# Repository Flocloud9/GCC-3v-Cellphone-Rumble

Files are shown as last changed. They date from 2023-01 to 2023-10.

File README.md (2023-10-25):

# **GCC-3v-Cellphone-Rumble**

3v Cellphone Rumble Bracket for the GCC and Phob GCC project.

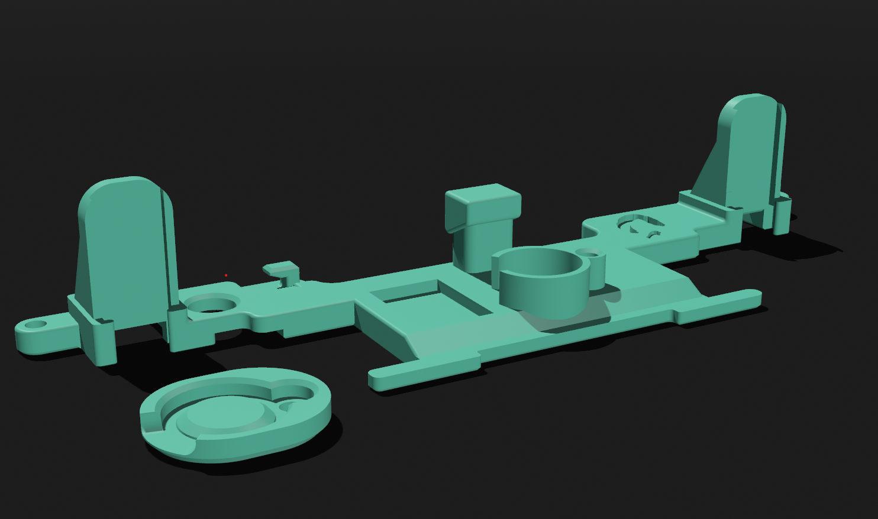
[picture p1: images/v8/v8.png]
Bracket Version 8!


## **An open source 3v "Cell-phone" Rumble Bracket for the PHOB & GCC with...**

-   compatible with either 3v Buck Converter or \~23 ohm resistor
-   Mouse click L/R compatibility
-   Cutout for OEM and snapback mod wires
-   L-cut hole for Phob 1.2.X teensy pins
-   Cell rumble mount with screw on lid
-   Open Source! Just throw me some credit on derivatives @abeartus :)
-   Shap3r editable files included!

## **required parts**

-   3-4x M1.6 Heat inserts [McMaster](https://www.mcmaster.com/92120A150/)

-   3-4x M1.6 Screw [McMaster](https://www.mcmaster.com/90910A901/)

-   1x 3v cellphone motor [Amazon](https://a.co/d/5VttFeg) [AliExpress](https://www.aliexpress.us/item/3256803801626556.html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)

*Pick one of the two methods for stepping down the controllers 5v out to the cell rumble's 3v*

**Resistor Method**

-   1x 25ohm resister [Amazon](https://a.co/d/4aCmpb3) (just need the 22ohm)

-   1x small 3:1 Heat shrink [Amazon](https://a.co/d/0B9l2j5)
 
**Buck Converter Bracket**

-   recommended : 1x 3v Buck converter not soldered [AliExpress](https://www.aliexpress.us/item/2251832865440609.html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)
-   or
-   1x 3v Buck converter pre soldered [Amazon](https://a.co/d/hcY47oe) [AliExpress](https://www.aliexpress.us/item/3256802643066285.html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,scm-url:1007.40000.317745.0,pvid:9f4be090-9cd5-447a-85e5-b2ded161dbb8,tpp_buckets:668%232846%238110%23324&pdp_ext_f=%7B%22sku_id%22%3A%2212000030781473442%22%2C%22sceneId%22%3A%2230050%22%7D&pdp_npi=2%40dis%21USD%210.01%210.01%21%21%21%21%21%402101f6b716734767897904494edef0%2112000030781473442%21rec)

## **Guide**

### **1. Get a copy of the Bracket and Lid printed**

-   I usually print in PLA+, However regular pla, and rigid resins should work for the bracket

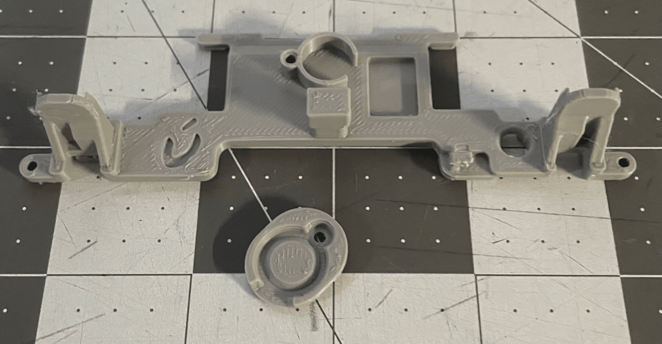
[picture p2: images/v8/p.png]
    

-   If printing on your own home machine with Cura I recommend doing support blocking around the L-cut on the bottom for the Phob 1's Teensy pins.

    1.  Select the bracket in Cura

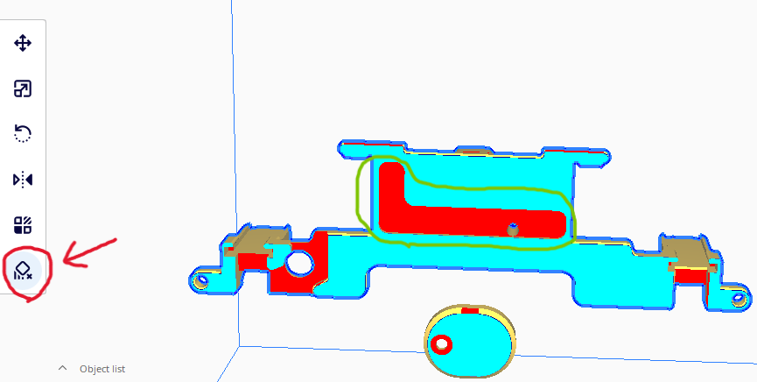
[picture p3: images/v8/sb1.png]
        

    2.  Put the support blocking around the L-Cut channel

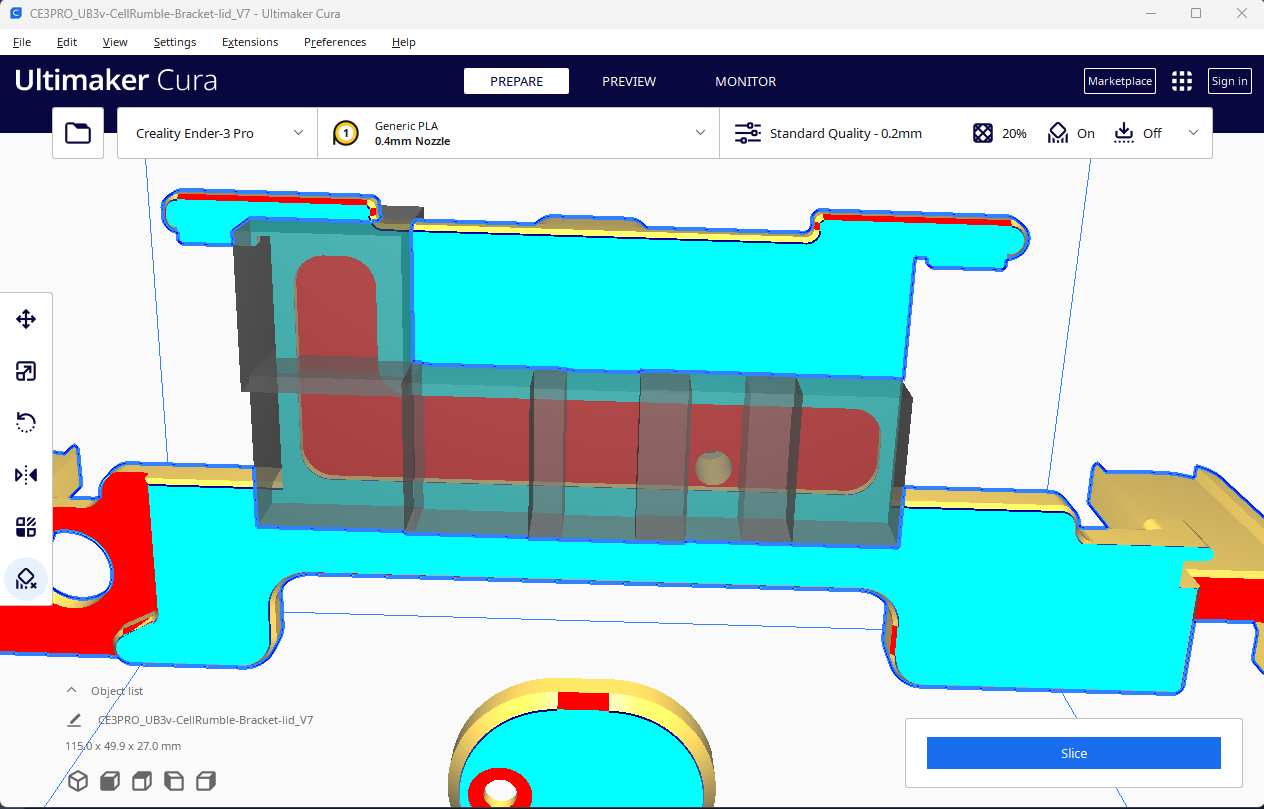
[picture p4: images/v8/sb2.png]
        

### **2. Prep the cellphone motor**

**!!** *Use one of the two methods to step down the 5v to 3v* **!!**

#### **Resistor**

  1.  Cut the motor lead short

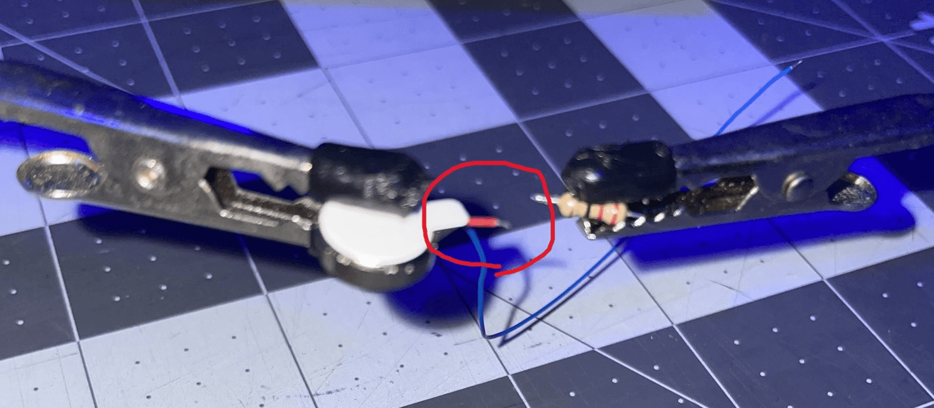
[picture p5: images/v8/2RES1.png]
      

  2.  splice in the \~23 ohm resistor

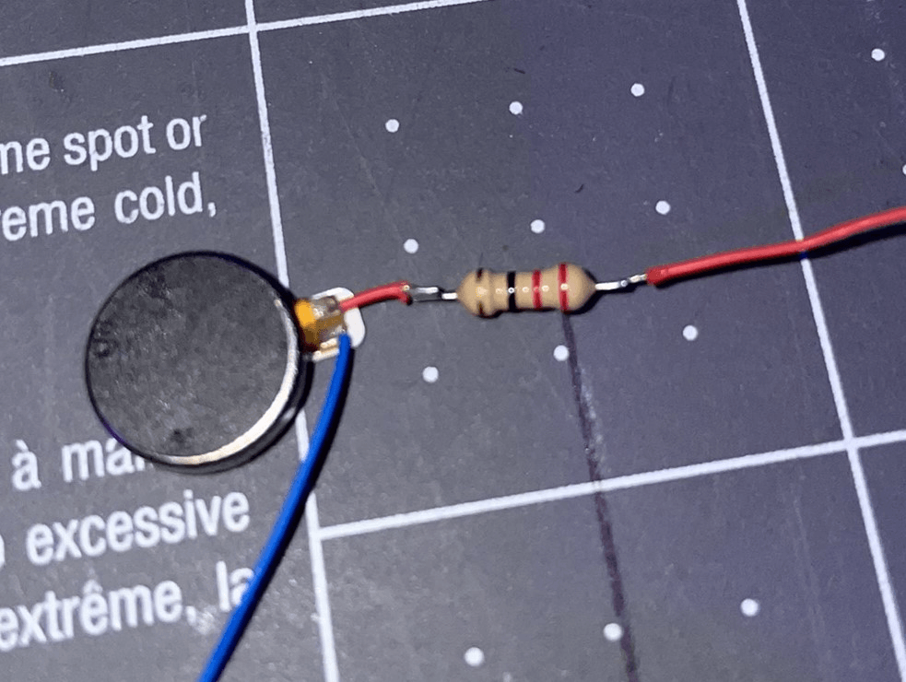
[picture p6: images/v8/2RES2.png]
      

  3.  Heat shrink over the connections/resistor

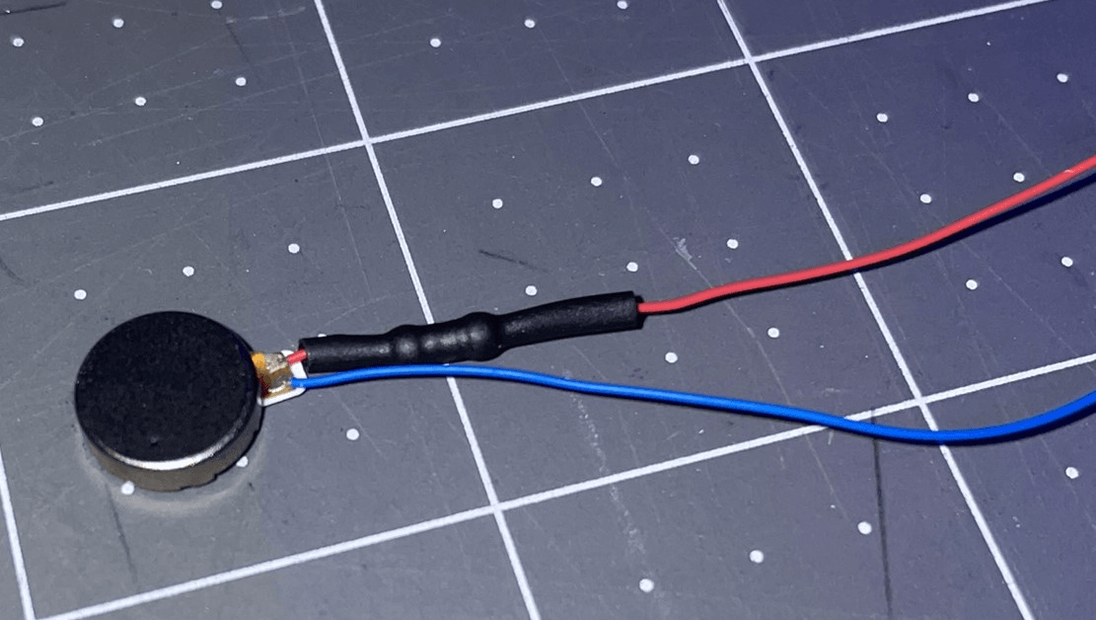
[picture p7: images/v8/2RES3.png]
      

#### **Buck Converter**

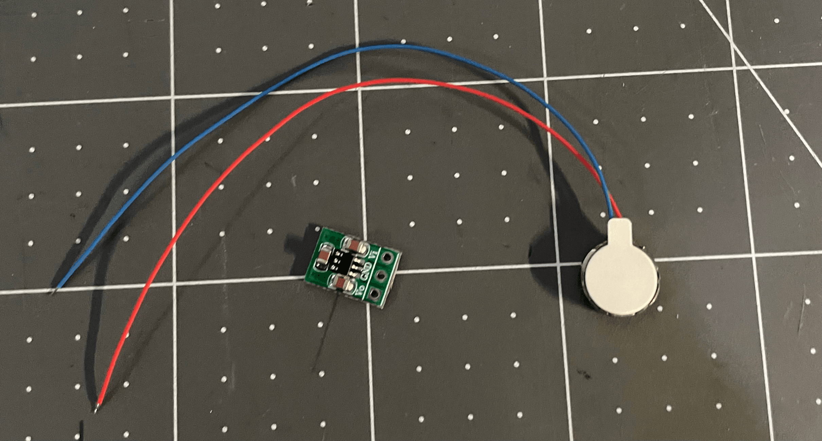
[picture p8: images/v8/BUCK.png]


  1.  Cut the motor leads short, I recycle the remaining wire for the other two connections *(you will need to buy the longer wire motor for this though)*

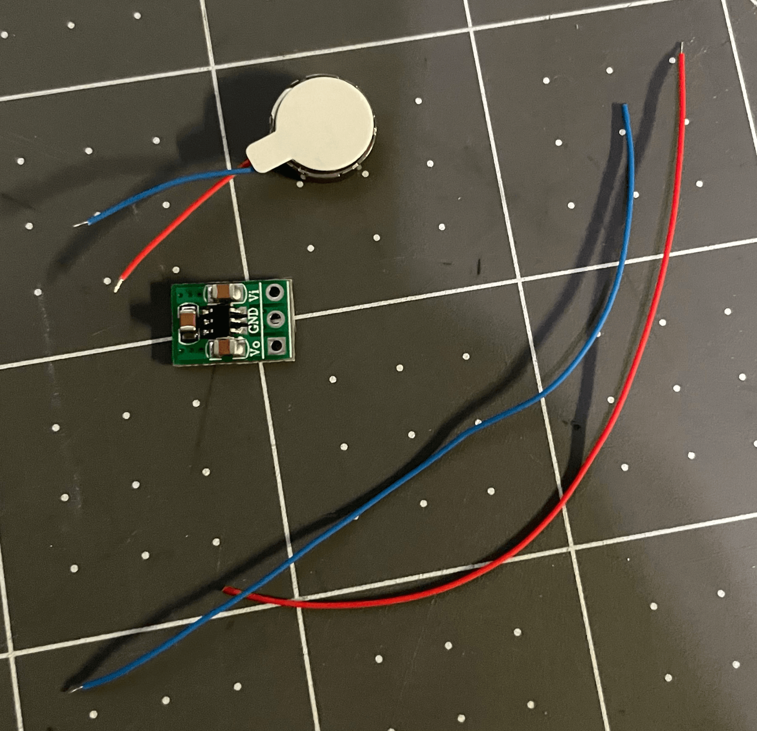
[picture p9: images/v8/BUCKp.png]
      

  2.  Solder the motor positive to the Buck Converter's **v**<sub>0 *(voltage out)*

  3.  Solder the motor negative, and another negative wire to the buck converter's **GND**

  4.  Solder a positive wire onto the Buck Converters **V**<sub>i *(Volatage in)*

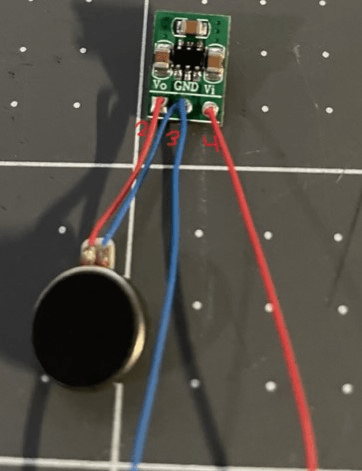
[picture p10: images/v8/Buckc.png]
      

  5.  Try to keep the bottom of the buck converter as flush as possible if using the smaller variety

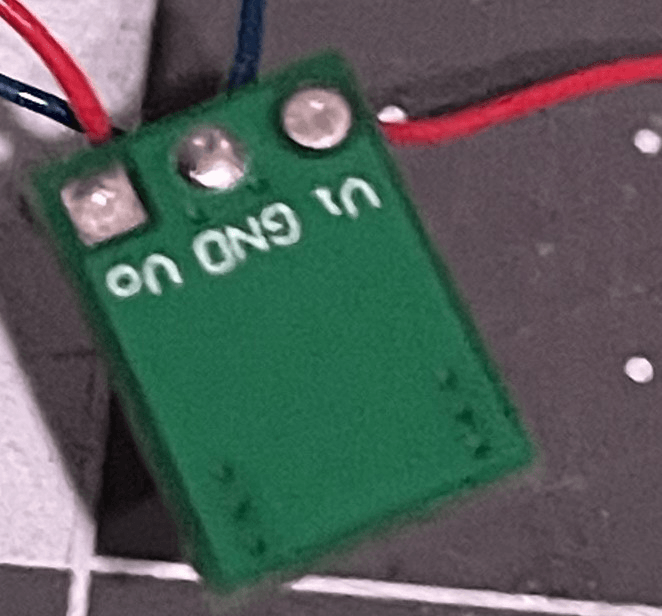
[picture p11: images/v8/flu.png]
      

### **3. Insert the motor into the bracket**

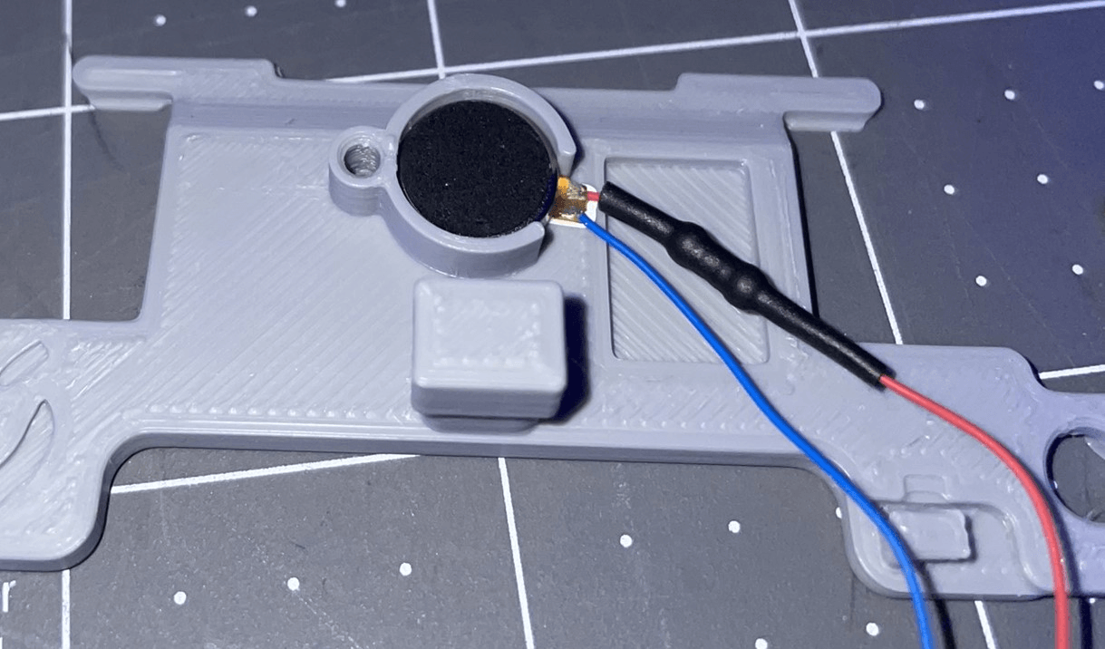
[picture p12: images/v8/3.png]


-   Extra step if using a buck converter

    1.  Glue the buck converter into the dugout to the right of the rumble housing. (I would recommend using some hot glue to hold it into place, super glue tends to ruin the buck converter for some reason when I use it)

### **4. Insert the Threaded Heat Inserts**

-   Using a soldering iron at around 200c or as low as possible with a small tip that can slot into the insert. push the three inserts into the Bracket.

-   The inserts should be pushed in on whatever side it will be screwed in from. So one pushed in from the top, and two on bottom. The proper side has a fillet around the slot that will make the insert easier to place at first.

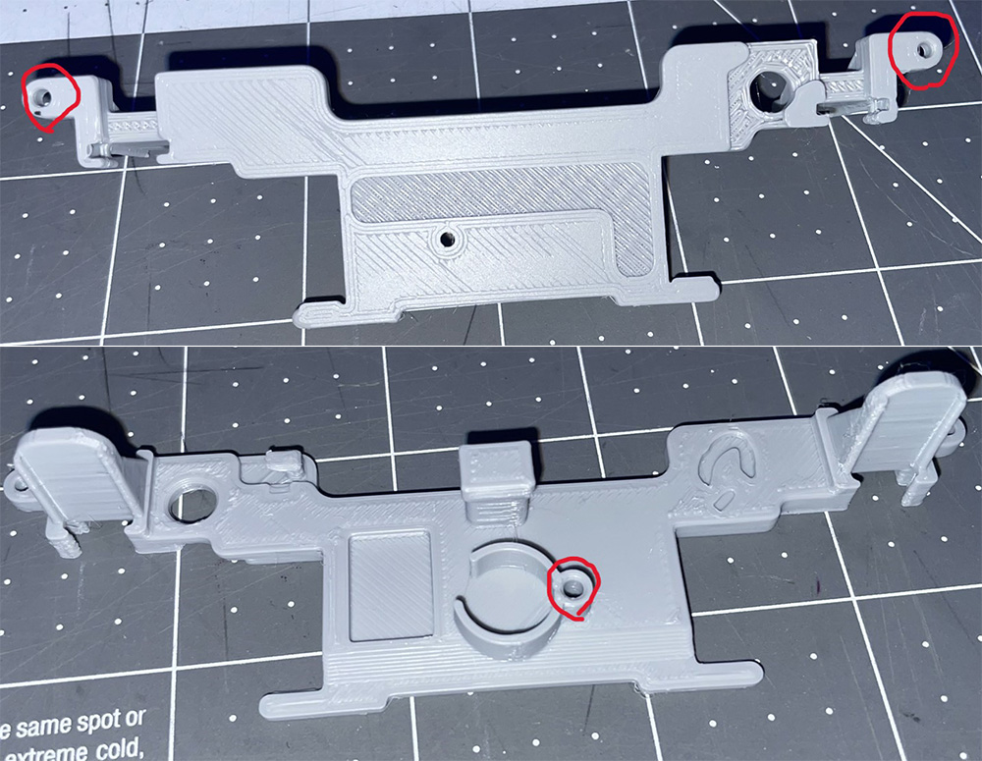
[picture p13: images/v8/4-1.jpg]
    

-   Personally I will set the insert into the brackets slot, then carefully push the insert in trying to be as perpendicular with the bracket as I can.

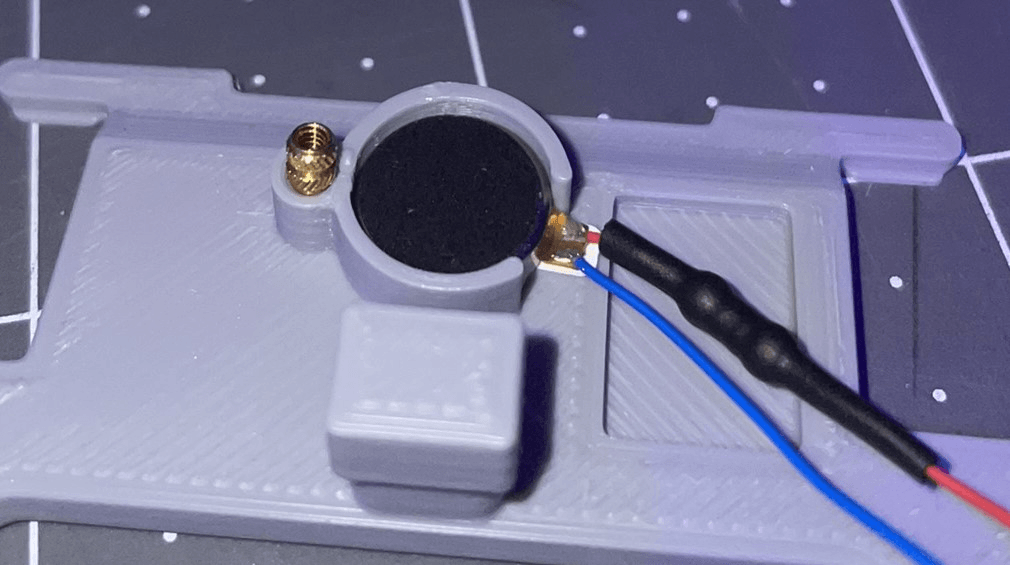
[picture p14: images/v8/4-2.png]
    

-   the bottom ones can be tricky, I usually just flip the bracket over and put the slotted tab onto the table, then I use the method above.

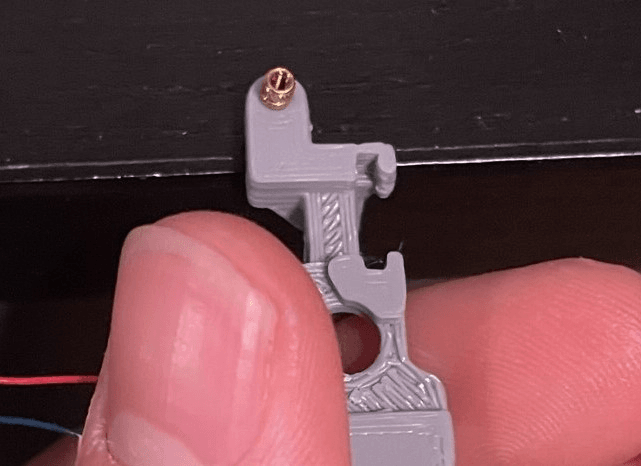
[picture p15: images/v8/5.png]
    

-   This Is what the threads should look like after insertion

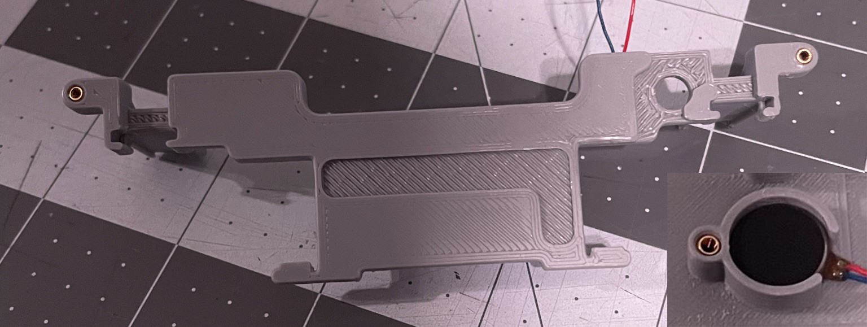
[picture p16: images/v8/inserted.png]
    

### **5. Attach the lid motor's lid to the Bracket**

1.  (semi-optional) I would recommend using some hot glue to help dampen any rattle from the lid and motor, and protect the short motor connection to the resistor.

    -   This is how I apply hot glue

    1.  *(only for my method of splicing in the resistor)* Put a small amount of glue here just to protect the wire from yanking and damaging the resistor splice and motor connection
    2.  *(optional)* Apply a light amount of hot glue here, then while the glue is hot press the rumble motor housing lid into place

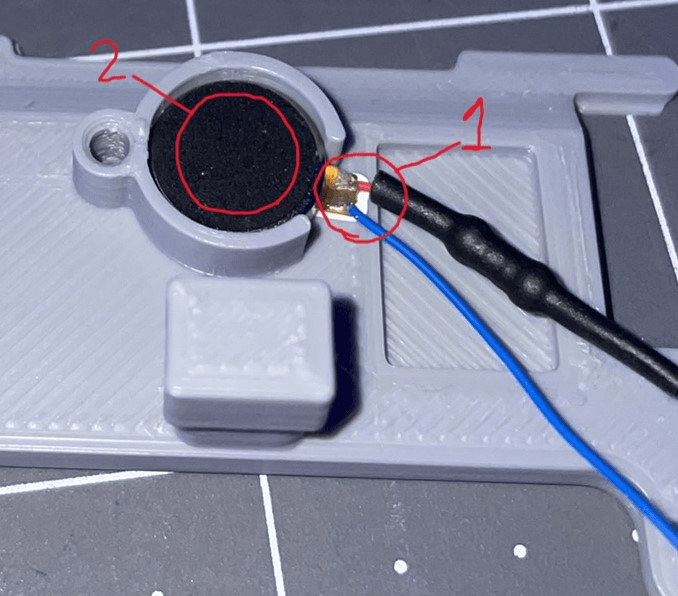
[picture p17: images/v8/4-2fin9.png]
    

2.  Screw the lid into place with one of the three m1.6 screws

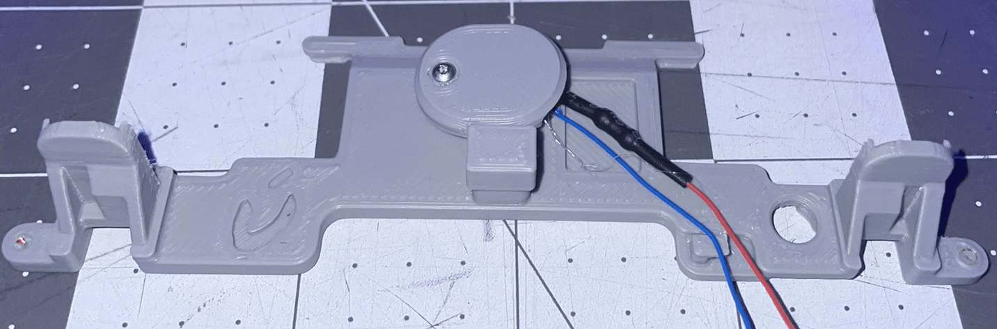
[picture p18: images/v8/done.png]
    

### **6. Solder the Bracket onto the board**

... just like oem ...

### **7. Attach the Bracket onto the board**

I clip the top wings over the L\R sliders then pull the bottom over and onto the pcb

### **8. Screw the bracket into place with the remaining two screws**

Screw it :))

## **Credit**

-   similar guide by fires on [his bracket](https://firescc.com/mod-guides#/rumble-bracket), mine is similar, so credit to fires

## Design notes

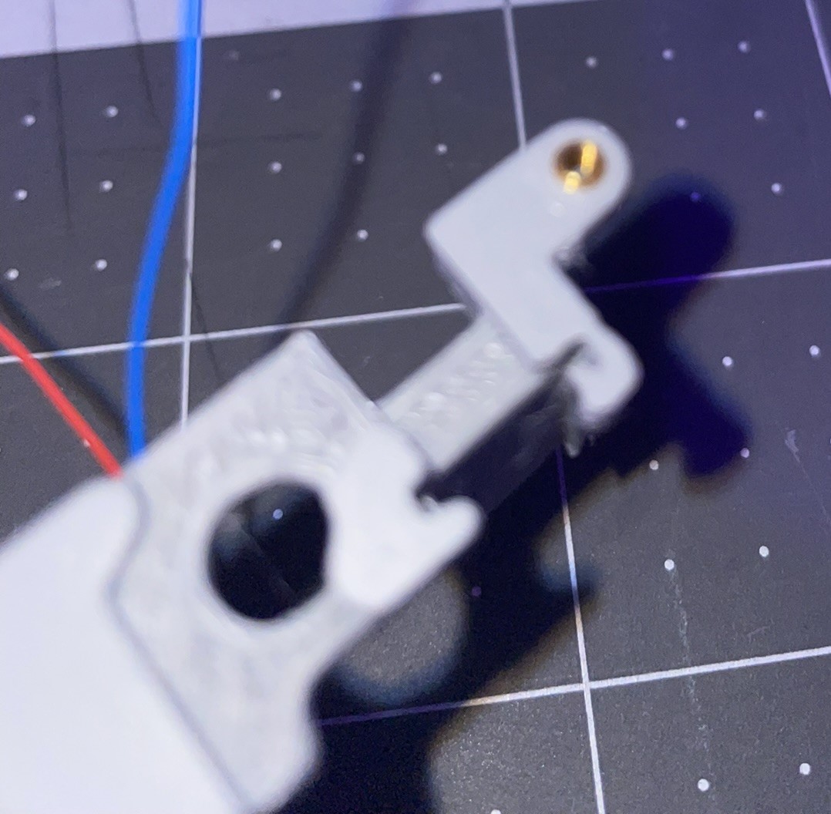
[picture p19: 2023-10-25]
images/v8/4botfin.JPEG

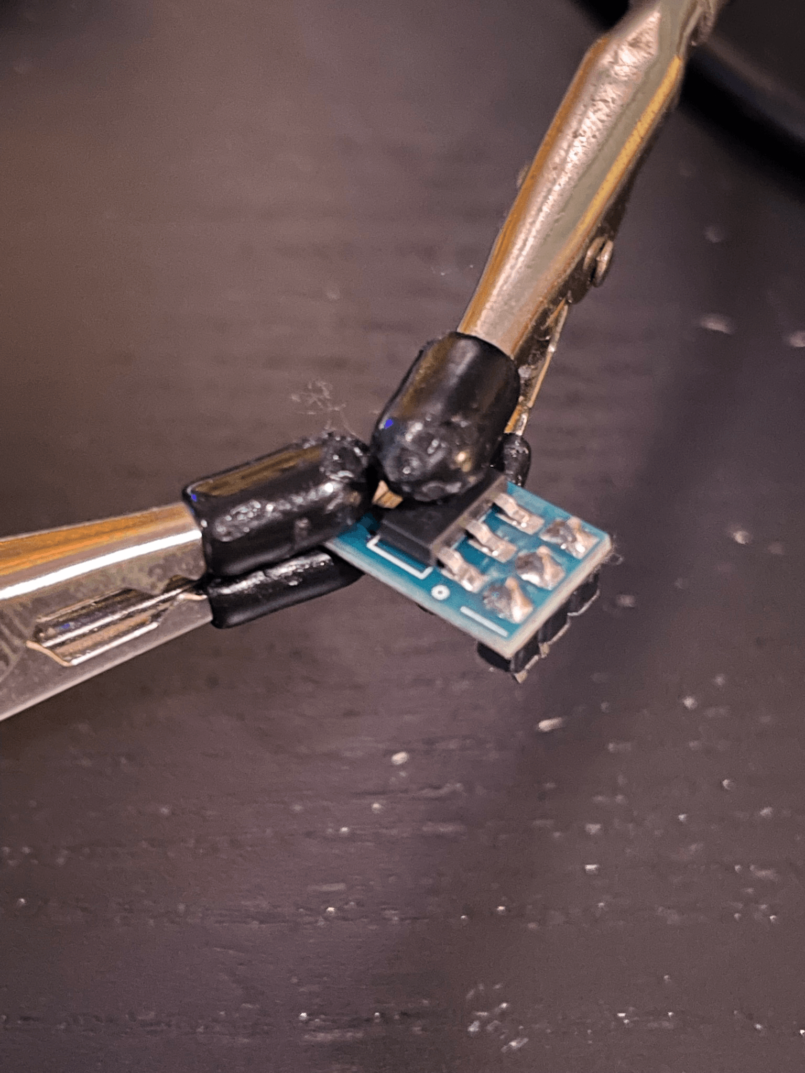
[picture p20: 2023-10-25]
images/v8/pin1.png

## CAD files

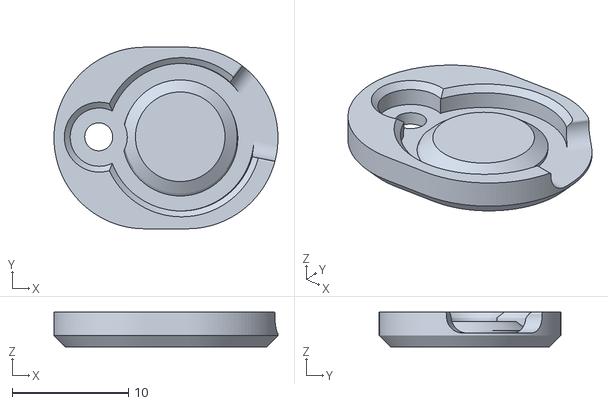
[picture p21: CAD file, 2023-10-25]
STL's/UB3v-CellRumble-Bracket-lid_V8.stl
19.2 x 15.6 x 3.00

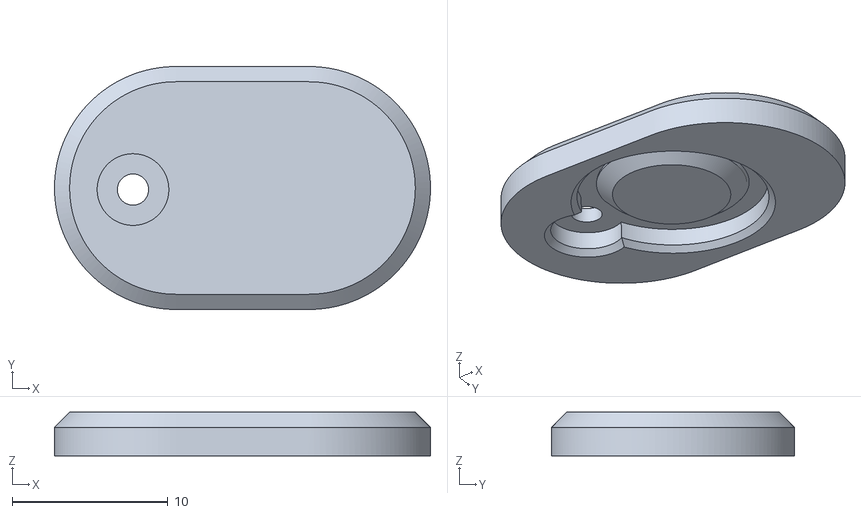
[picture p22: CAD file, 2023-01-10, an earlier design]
Legacy/STL's/V1/UB3V_Cell-Lid_V1.stl
24.1 x 15.6 x 2.80

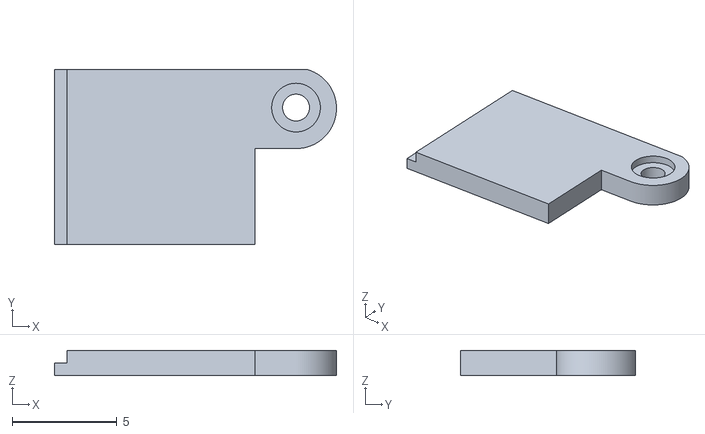
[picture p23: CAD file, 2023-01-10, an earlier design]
Legacy/STL's/V2/UB3V_Buck-Lid_V2.stl
13.4 x 8.33 x 1.20

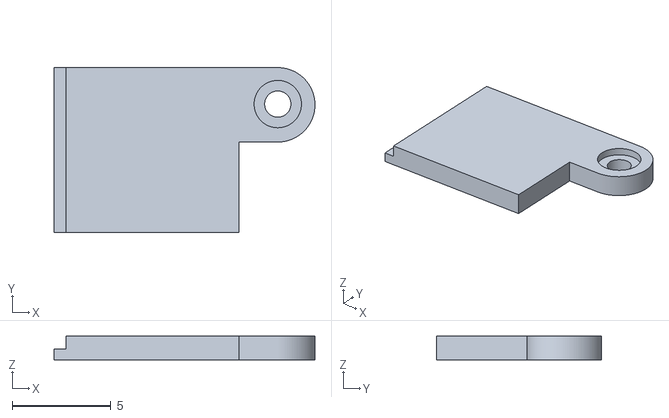
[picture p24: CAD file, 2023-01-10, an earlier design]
Legacy/STL's/V3/UB3V_Buck-Lid_V3.stl
13.2 x 8.33 x 1.20

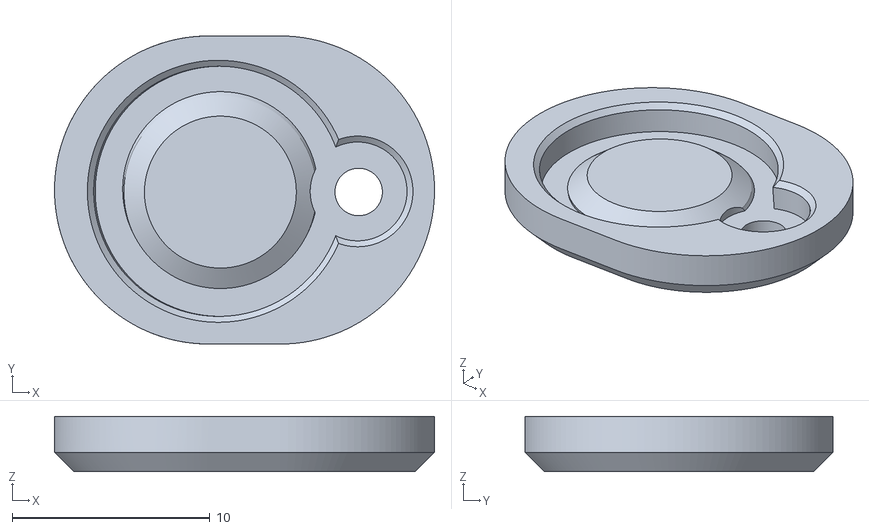
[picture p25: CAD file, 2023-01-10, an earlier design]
Legacy/STL's/V4/UB3V_Cell-Lid_V4.stl
19.2 x 15.6 x 2.80

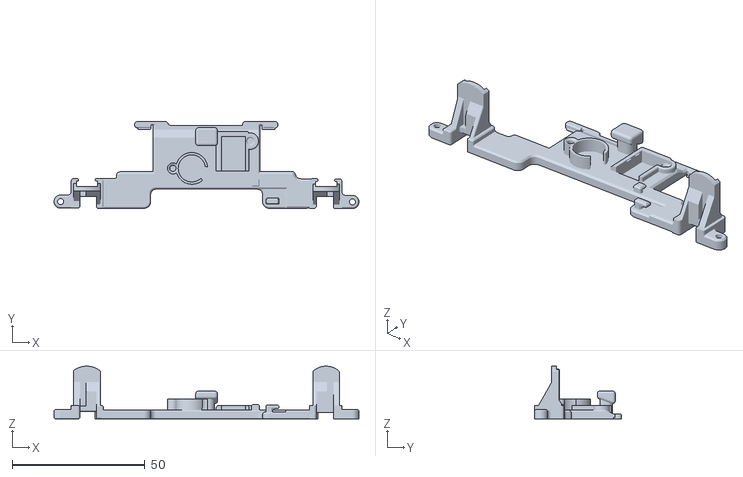
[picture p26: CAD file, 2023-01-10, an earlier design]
Legacy/STL's/V1/UB3V_Bracket_V1.stl
115.1 x 32.9 x 19.9

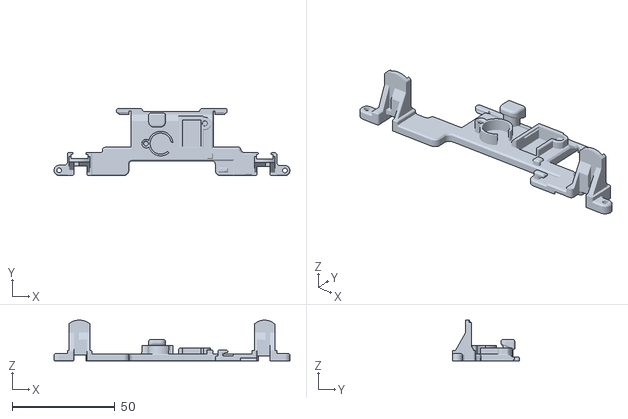
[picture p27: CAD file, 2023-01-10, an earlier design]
Legacy/STL's/V2/UB3V_Bracket_V2.stl
115.1 x 32.9 x 19.9

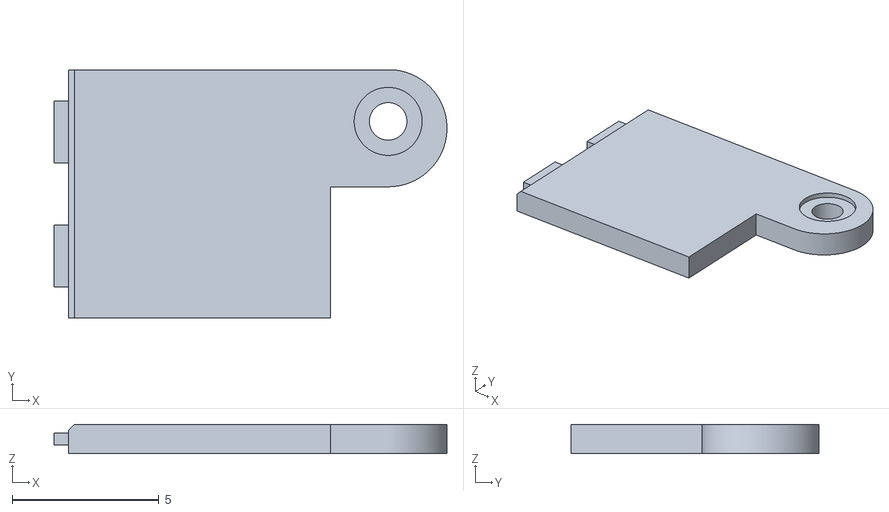
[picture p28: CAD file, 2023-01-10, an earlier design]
Legacy/STL's/V1/UB3V_Buck-Lid_V1.stl
13.4 x 8.48 x 1.00

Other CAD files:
Legacy/STL's/V5/Buck Module Bracket/UB3V_Cell-Lid_V5.stl
Legacy/STL's/V5/Classic Bracket/UB3V_Classic-Cell-Lid_V5.stl
Legacy/STL's/v6/UB3v-CellRumble-Bracket-lid_V6.stl
Legacy/STL's/V4/UB3V_Buck-Lid_V4.stl
Legacy/STL's/V5/Buck Module Bracket/UB3V_Buck-Lid_V5.stl
Legacy/STL's/V2/UB3V_Cell-Lid_V.stl

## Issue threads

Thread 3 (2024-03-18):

Please add STEP Files!!!

Dracrius, 2024-03-18:
I can not believe that a bracket designed for an open source board posted to be supposedly open source only has a proprietary file format used for source file...

Shapr3D is an absolute garbage pile. I had to go through a 5min tutorial that is impossible to skip, teaching me shit I already know from every other damn CAD. Then you have to sign up for an account and even then I can't export the model as a step file without a Subscription! You can't even export a quality 3mf or stl which is just insane. I'm not signing up for a free trial either and giving them a credit card just for them to charge when I forget!! These are hard core dark patterns I don't even want this software on my computer.

It is clear based on the quality of the stl's you personally must own a license to Shapr3D so could I beg you to please export the project as step files so that others can import it into ANY CAD software?

The stl isn't enough I really don't want to deal with all these tri's.
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

Dracrius, 2024-03-18:
I want to be able to fill in the box that isn't needed and make a few other tweaks that should only take me 5min but it's going to take over an hour if I keep at it at this rate because the tri's make Fusion360 real hard to work with as it has to hang for a minute at a time to figure out what it is doing only for you to find out it can't make that change because of some other random tri!

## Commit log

2023-01-10 Hello world
    files migrated and basic bracket release files added
    [UB3V_Bracket_V1.stl, UB3V_Bracket_V2.stl, UB3V_Buck-Lid_V1.stl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]
2023-06-09 V6 added
    All files added
    [UB3V_Buck-Lid_V5.stl, UB3V_Cell-Lid_V5.stl, UB3V_Classic-Cell-Lid_V5.stl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]
2023-06-13 Guide updated
    Still needs polishing but were close
    [UB3v-CellRumble-Bracket-lid_V6.stl, UB3v-CellRumble-Bracket-lid_V7.stl]
2023-10-25 Guide finished
    V8 added with documentation
    [UB3v-CellRumble-Bracket-lid_V6.stl, UB3v-CellRumble-Bracket-lid_V7.stl, UB3v-CellRumble-Bracket-lid_V8.stl]
